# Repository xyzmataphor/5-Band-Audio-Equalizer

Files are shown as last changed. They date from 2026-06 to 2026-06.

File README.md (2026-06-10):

# 5-Band-Audio-Equalizer
This project presents the complete design and simulation of a 5-band analog graphic audio equalizer using the Active Inverting Bandpass Filter topology with LT1022 operational amplifiers in simulation and NE5532 for the physical PCB implementation. The equalizer is designed to independently control five frequency bands spanning the full audio range from 60 Hz to 16 kHz, making it suitable for music playback, recording, and general audio signal processing applications.

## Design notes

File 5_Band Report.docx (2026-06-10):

+OVERVIEW

This project presents the complete design and simulation of a 5-band analog graphic audio equalizer using the Active Inverting Bandpass Filter topology with LT1022 operational amplifiers in simulation and NE5532 for the physical PCB implementation. The equalizer is designed to independently control five frequency bands spanning the full audio range from 60 Hz to 16 kHz, making it suitable for music playback, recording, and general audio signal processing applications.

BLOCK DIAGRAM

Audio Input → [Input Buffer] → [5x BPF + Gain Pot] → [Summing Amplifier] → [Output Buffer] → Audio Output

DESIGN EQUATIONS

Center Frequency

f0 = 1 / ( 2π × sqrt( C1 × C2 × Rin × Rf ) )

Quality Factor

Q=0.5x sqrt(c1/c2)

CIRCUIT DIAGRAM

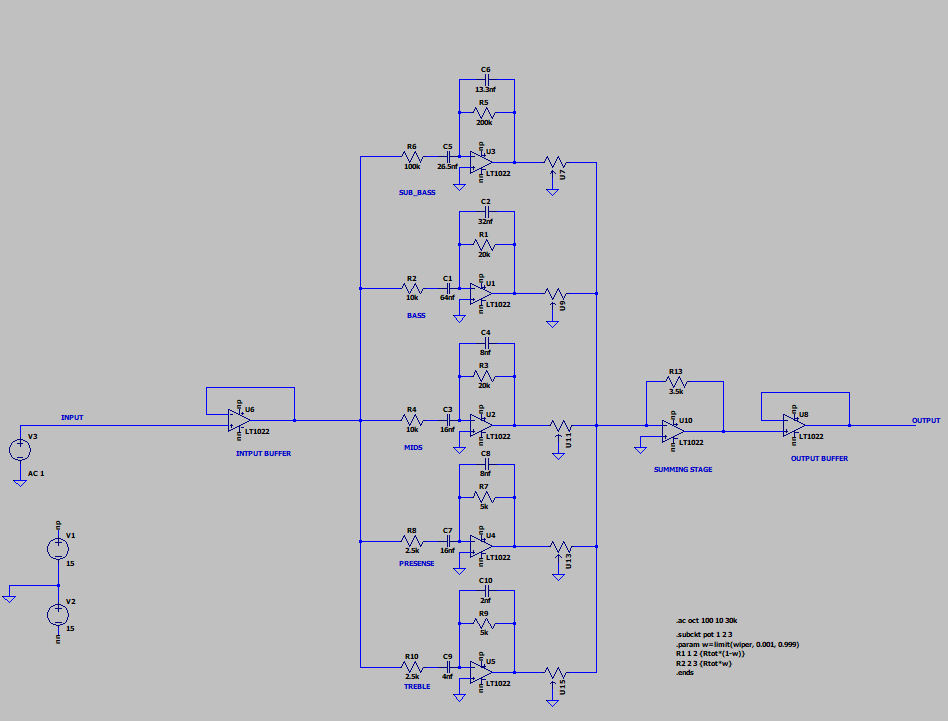
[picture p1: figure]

TRANSIENT ANALYSIS

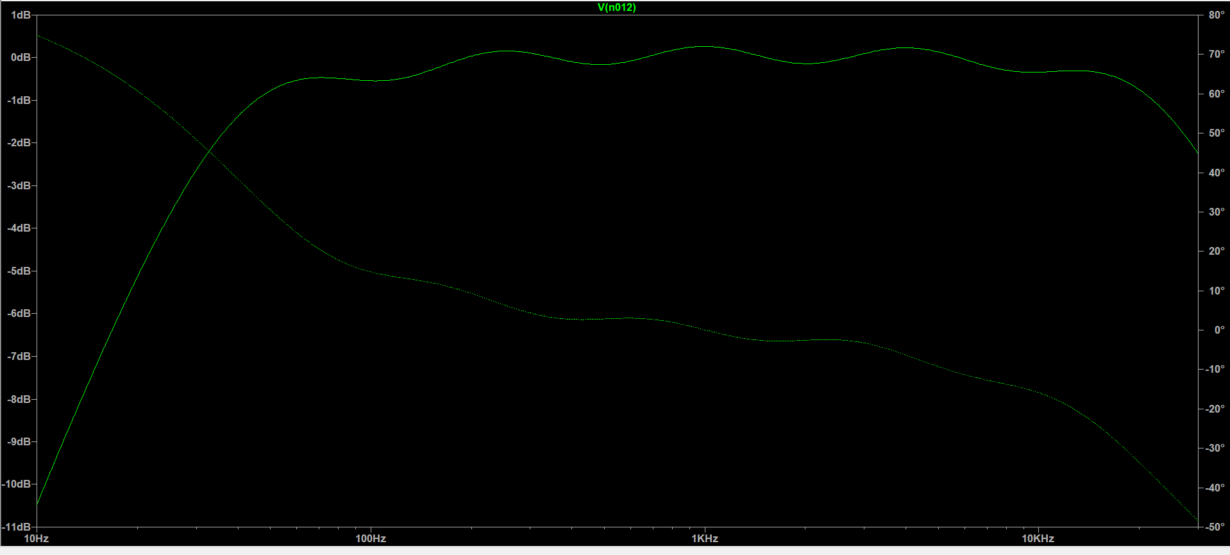
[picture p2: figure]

SCHEMATIC DIAGRAM

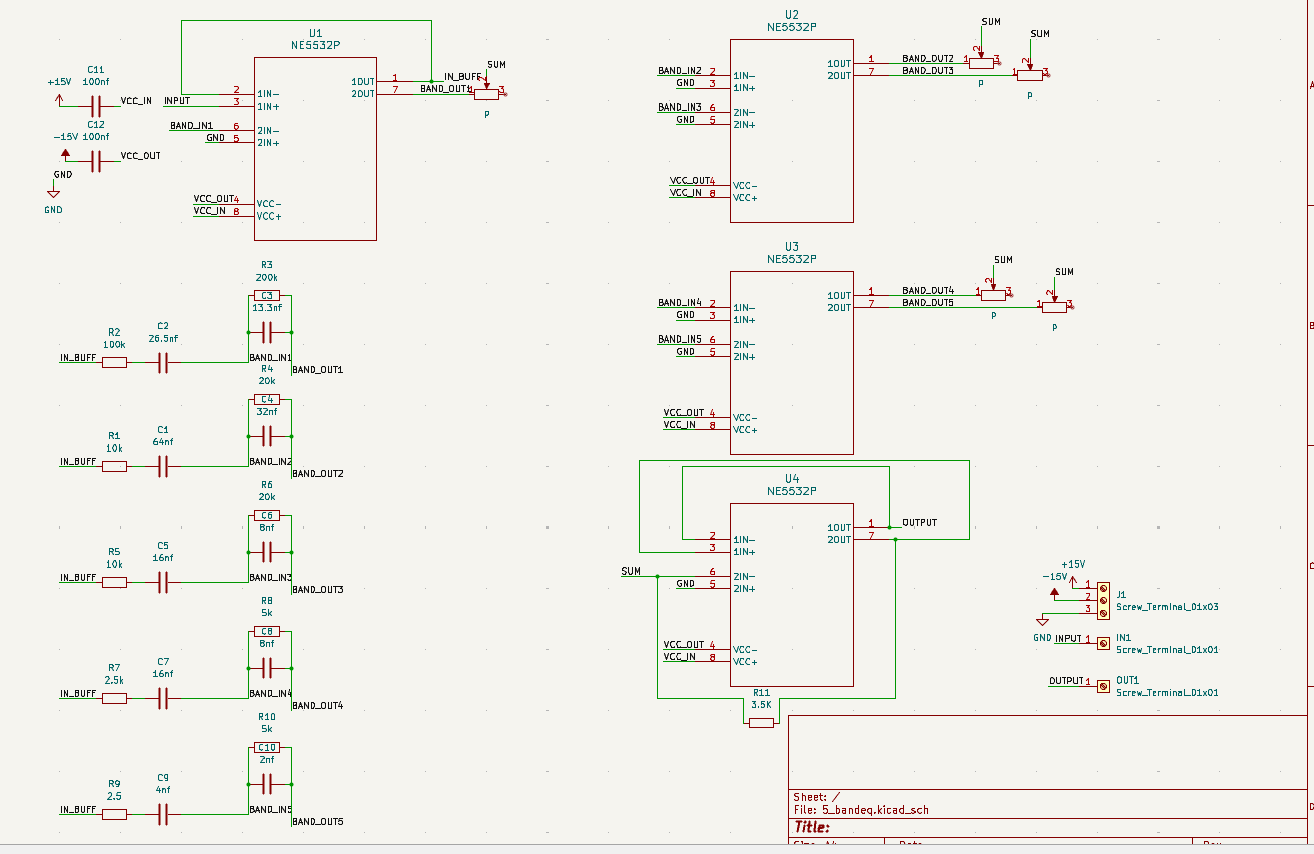
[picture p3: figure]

PCB LAYOUT

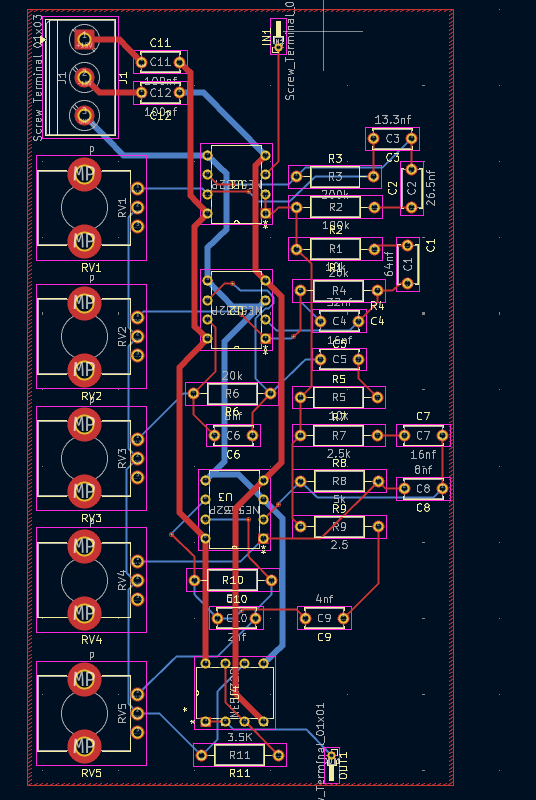
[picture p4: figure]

TOOLS USE

1. LTSPICE
2. KICAD

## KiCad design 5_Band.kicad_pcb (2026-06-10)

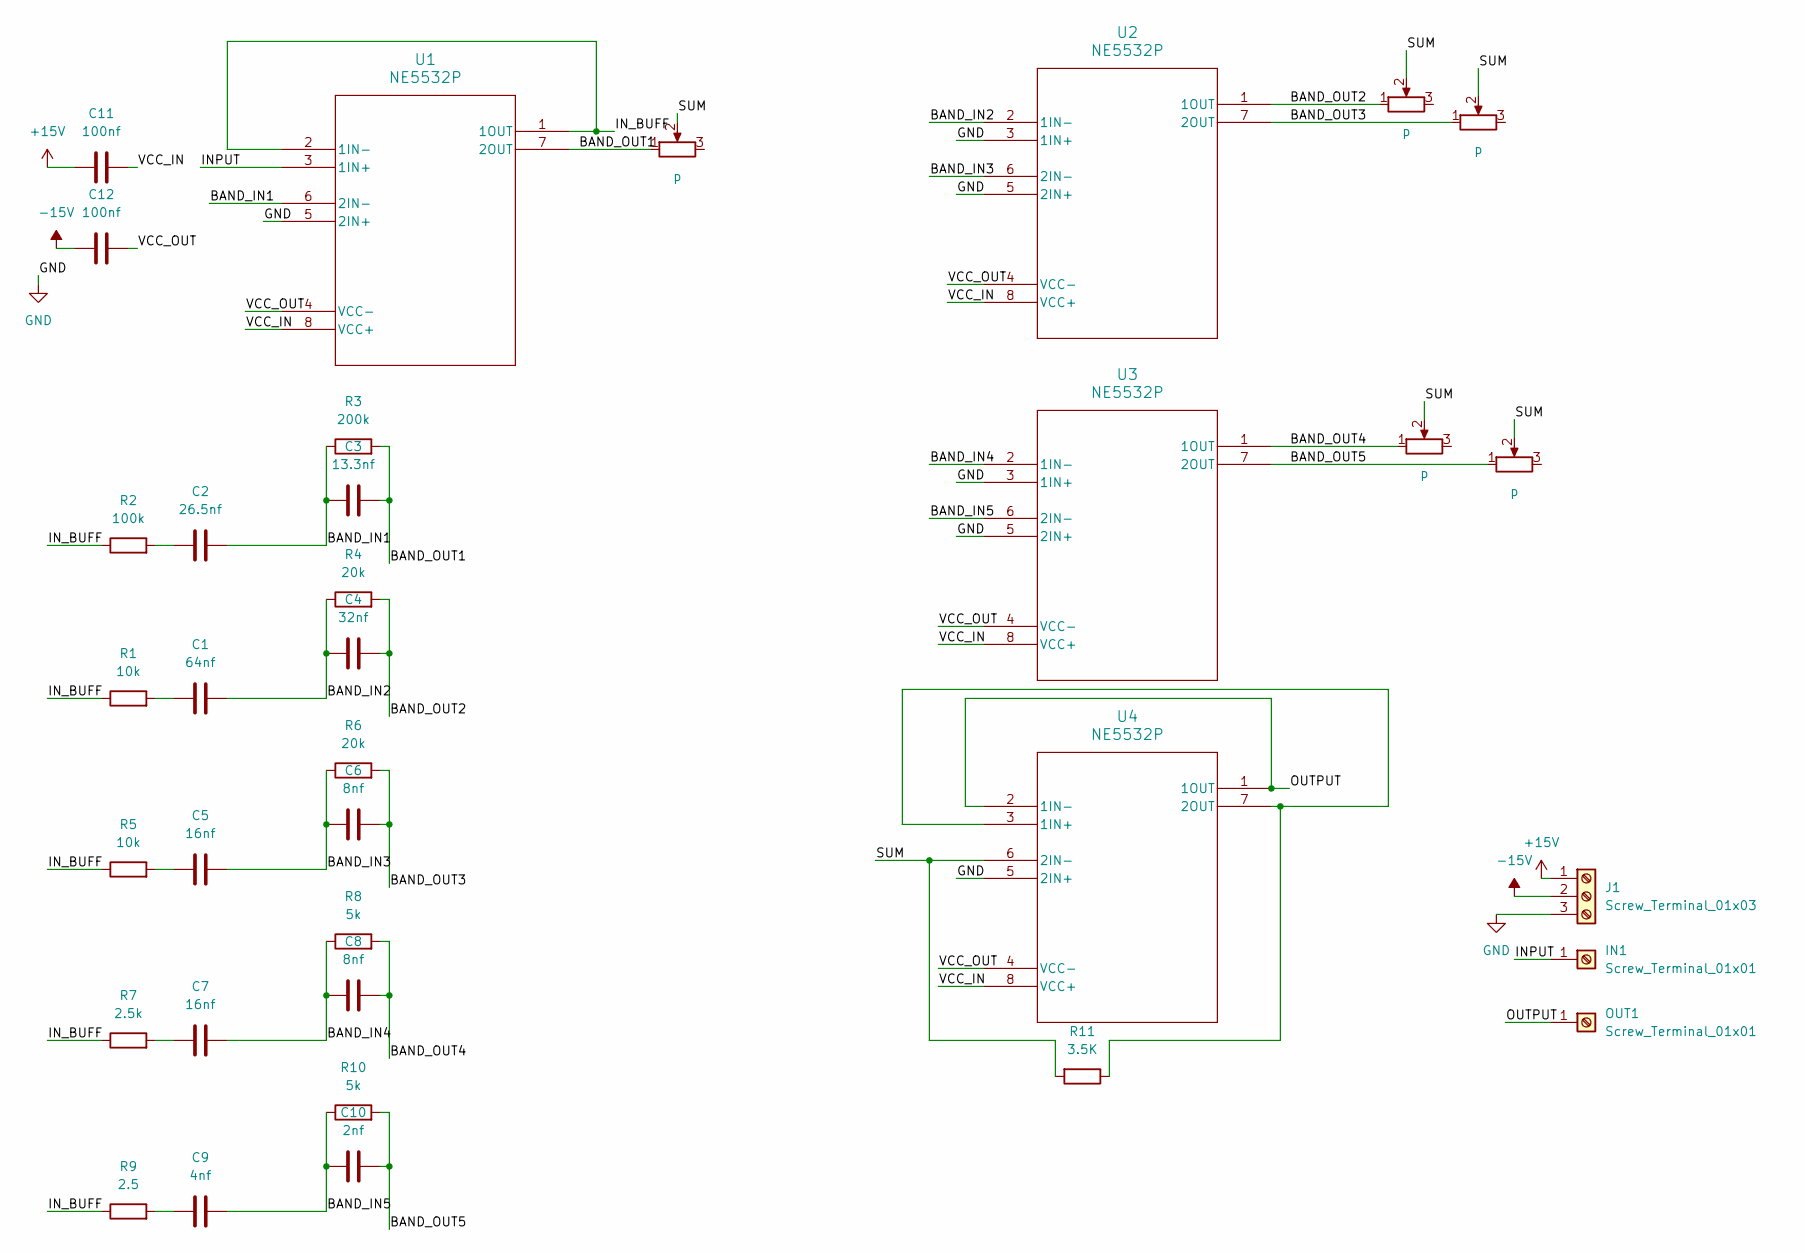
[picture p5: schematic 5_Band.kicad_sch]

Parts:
C1: 64nf; C_Disc_D5.0mm_W2.5mm_P5.00mm
C2: 26.5nf; C_Disc_D5.0mm_W2.5mm_P5.00mm
C3: 13.3nf; C_Disc_D5.0mm_W2.5mm_P5.00mm
C4: 32nf; C_Disc_D5.0mm_W2.5mm_P5.00mm
C5, C7: 16nf; C_Disc_D5.0mm_W2.5mm_P5.00mm
C6, C8: 8nf; C_Disc_D5.0mm_W2.5mm_P5.00mm
C9: 4nf; C_Disc_D5.0mm_W2.5mm_P5.00mm
C10: 2nf; C_Disc_D5.0mm_W2.5mm_P5.00mm
C11, C12: 100nf; C_Disc_D5.0mm_W2.5mm_P5.00mm
IN1: Screw_Terminal_01x01; PinHeader_1x01_P1.00mm_Horizontal
J1: Screw_Terminal_01x03; TerminalBlock_Phoenix_PT-1,5-3-5.0-H_1x03_P5.00mm_Horizontal
OUT1: Screw_Terminal_01x01; PinHeader_1x01_P1.00mm_Horizontal
R1, R5: 10k; R_Axial_DIN0207_L6.3mm_D2.5mm_P10.16mm_Horizontal
R2: 100k; R_Axial_DIN0207_L6.3mm_D2.5mm_P10.16mm_Horizontal
R3: 200k; R_Axial_DIN0207_L6.3mm_D2.5mm_P10.16mm_Horizontal
R4, R6: 20k; R_Axial_DIN0207_L6.3mm_D2.5mm_P10.16mm_Horizontal
R7: 2.5k; R_Axial_DIN0207_L6.3mm_D2.5mm_P10.16mm_Horizontal
R8, R10: 5k; R_Axial_DIN0207_L6.3mm_D2.5mm_P10.16mm_Horizontal
R9: 2.5; R_Axial_DIN0207_L6.3mm_D2.5mm_P10.16mm_Horizontal
R11: 3.5K; R_Axial_DIN0207_L6.3mm_D2.5mm_P10.16mm_Horizontal
RV1, RV2, RV3, RV4, RV5: p; Potentiometer_Bourns_PTV09A-1_Single_Vertical
U1, U2, U3, U4: NE5532P; P8

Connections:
+15V: C11.1, J1.1
-15V: C12.1, J1.2
/BAND_IN1: C2.2, C3.1, R3.1, U1.6 (2IN-)
/BAND_IN2: C1.2, C4.1, R4.1, U2.2 (1IN-)
/BAND_IN3: C5.2, C6.1, R6.1, U2.6 (2IN-)
/BAND_IN4: C7.2, C8.1, R8.1, U3.2 (1IN-)
/BAND_IN5: C9.2, C10.1, R10.1, U3.6 (2IN-)
/BAND_OUT1: C3.2, R3.2, RV1.1, U1.7 (2OUT)
/BAND_OUT2: C4.2, R4.2, RV2.1, U2.1 (1OUT)
/BAND_OUT3: C6.2, R6.2, RV3.1, U2.7 (2OUT)
/BAND_OUT4: C8.2, R8.2, RV4.1, U3.1 (1OUT)
/BAND_OUT5: C10.2, R10.2, RV5.1, U3.7 (2OUT)
/INPUT: IN1.1, U1.3 (1IN+)
/IN_BUFF: R1.1, R2.1, R5.1, R7.1, R9.1, U1.1 (1OUT), U1.2 (1IN-)
/OUTPUT: OUT1.1, U4.1 (1OUT), U4.2 (1IN-)
/SUM: R11.2, RV1.2, RV2.2, RV3.2, RV4.2, RV5.2, U4.6 (2IN-)
/VCC_IN: C11.2, U1.8 (VCC+), U2.8 (VCC+), U3.8 (VCC+), U4.8 (VCC+)
/VCC_OUT: C12.2, U1.4 (VCC-), U2.4 (VCC-), U3.4 (VCC-), U4.4 (VCC-)
GND: J1.3, U1.5 (2IN+), U2.3 (1IN+), U2.5 (2IN+), U3.3 (1IN+), U3.5 (2IN+), U4.5 (2IN+)
unnamed: C1.1, R1.2
unnamed: C2.1, R2.2
unnamed: C5.1, R5.2
unnamed: C7.1, R7.2
unnamed: C9.1, R9.2
unnamed: R11.1, U4.3 (1IN+), U4.7 (2OUT)

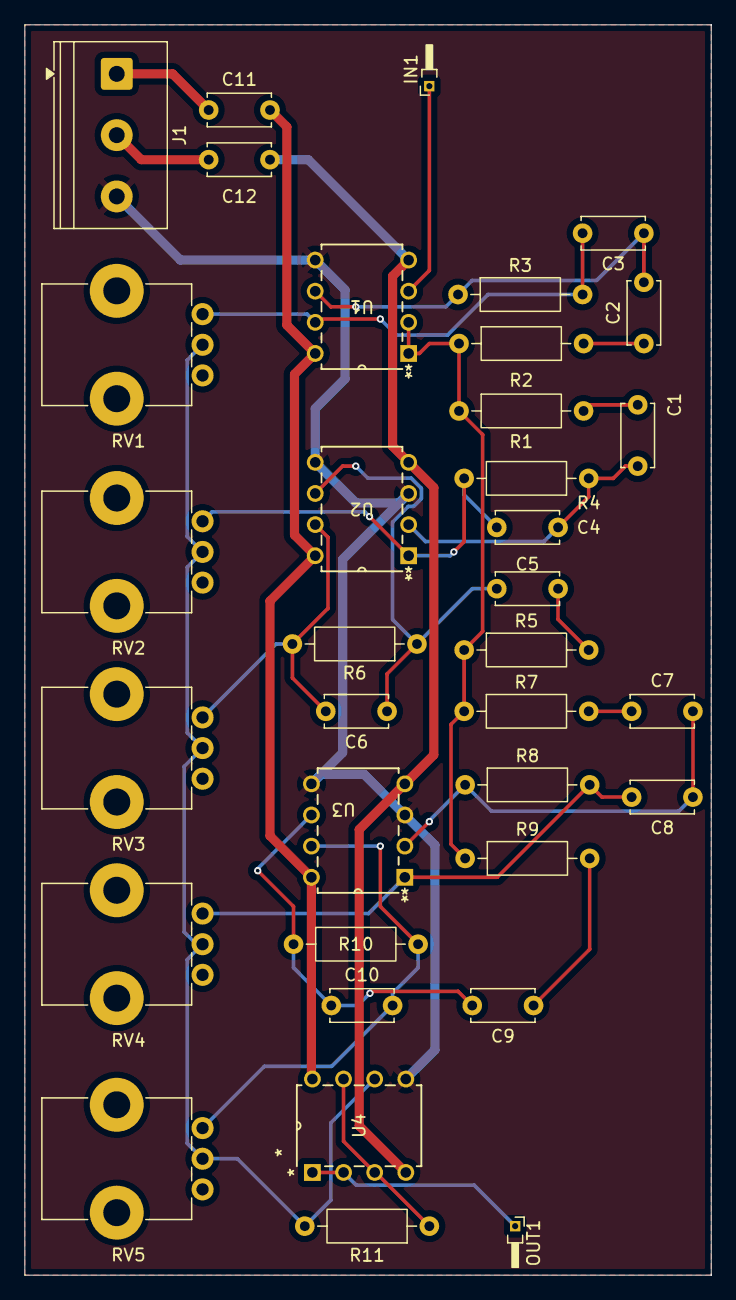
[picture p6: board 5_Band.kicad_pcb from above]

Board: 2 copper layers, 56.0 x 102.0 mm, 35 parts (0 on the bottom side), 25 nets.
